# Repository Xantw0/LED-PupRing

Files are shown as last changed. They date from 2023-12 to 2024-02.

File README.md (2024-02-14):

<p align="center"> 
 
</p>

# 🌈 LED-PupRing
A collection of 3D files and build instructions to build a LED Nose Ring for neoprene Pup Masks



# 🛠 How to build?
Please check the [How-To guide](HOWTO.md) on build instructions and bill of materials

# 🤔 Too lazy to build yourself?
**I can probably help you out!**

I'll probably open my services every now and then, but do check this [Mastodon post](https://rubber.social/@Xantw0/111569252257938835) for more info on price, availability and contact info.

# ✨ Thanks
This project was inpired by [gdog](https://woof.group/@gdog) and Icteryn from this [Mastodon post](https://woof.group/@gdog/111154452751612377). I was playing around in Fusion360 and that got me to learn FreeCAD, so the logical thing was to share this dumb project with you too.

Also thanks to [Hex](https://linktr.ee/puphex) for his help showing me pictures and refrences of some of his hoods to make sure my mesurements were correct!

# ⚖ License
  <p xmlns:cc="http://creativecommons.org/ns#" xmlns:dct="http://purl.org/dc/terms/"><a property="dct:title" rel="cc:attributionURL" href="https://github.com/Xantw0/LED-PupRing">LED-PupRing</a> by <a rel="cc:attributionURL dct:creator" property="cc:attributionName" href="https://xantw0.link">Xantw0</a> is licensed under <a href="http://creativecommons.org/licenses/by-sa/4.0/?ref=chooser-v1" target="_blank" rel="license noopener noreferrer" style="display:inline-block;">Attribution-ShareAlike 4.0 International</a></p>

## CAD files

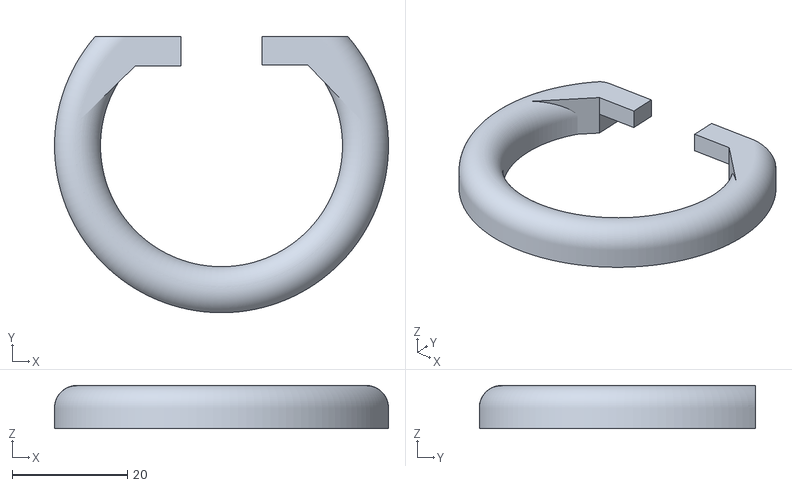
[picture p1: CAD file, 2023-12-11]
Print Files/NoseRingLED-Full.stl
58.0 x 48.0 x 7.50

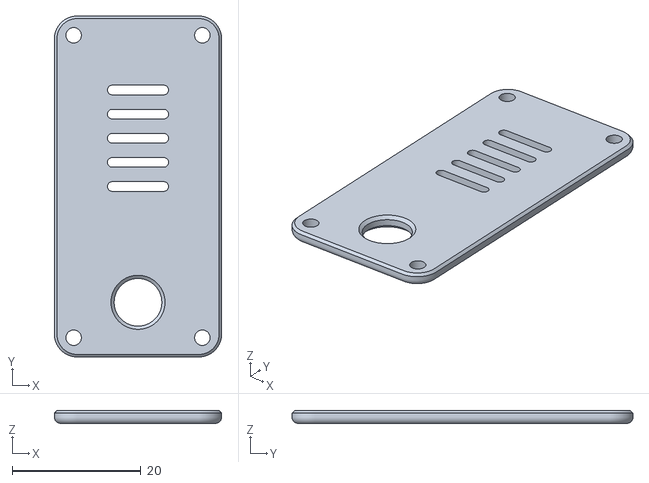
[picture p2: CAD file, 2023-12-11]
Print Files/NoseRingBox-Lid.stl
26.0 x 53.0 x 2.00

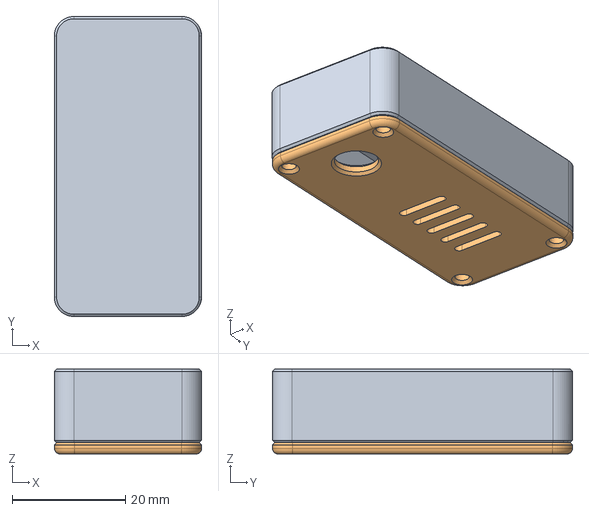
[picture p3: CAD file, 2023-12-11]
Source/NoseRingBox.FCStd
26.0 x 53.0 x 15.0 mm
Lid

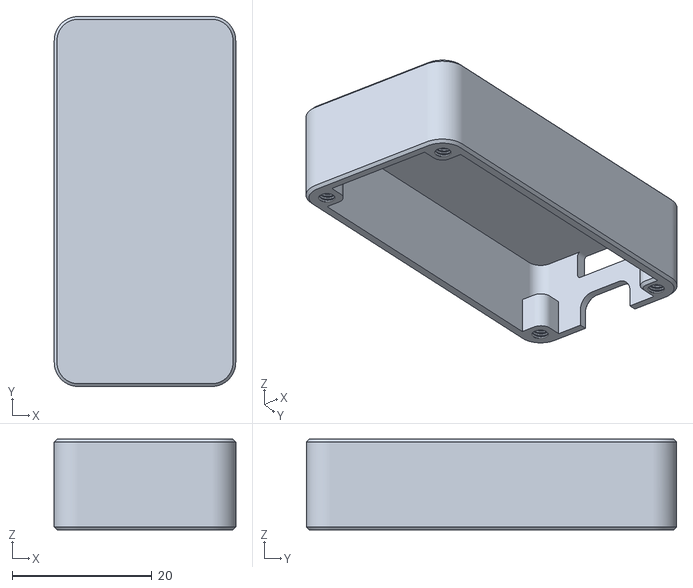
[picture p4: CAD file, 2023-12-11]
Print Files/NoseRingBox-Box.stl
26.0 x 53.0 x 13.0

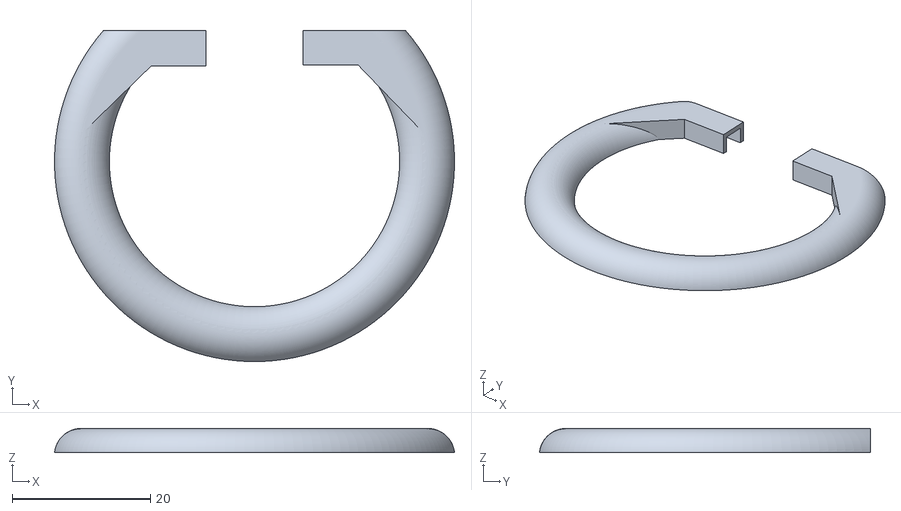
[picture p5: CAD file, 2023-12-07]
Print Files/NoseRingLED-Top.stl
57.9 x 48.0 x 3.50

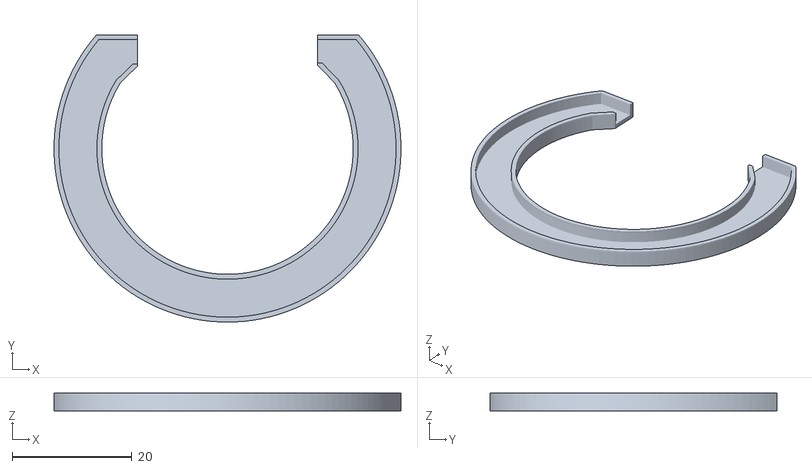
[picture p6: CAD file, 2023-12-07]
Print Files/NoseRingLED-Bottom.stl
58.0 x 48.0 x 3.00

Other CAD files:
Source/NoseRingLED.FCStd

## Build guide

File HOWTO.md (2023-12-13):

# Table of Content

1. [Bill of Material](#bill-of-material)
2. [Print Instructions](#print-instructions)
3. [Assembly Instruction](#assembly-instructions)
4. [Putting the Nose Ring on](#putting-the-nose-ring-on)

# Bill of Material
(Note: All of the link are **NOT** affiliated, I do not make money if you use these. Feel free to source your components elsewhere 😉)
<p align="center"> 

| Item | Amount | Price |
| --- | --- | --- |
| [Seeed Studio XIAO ESP32C3](https://vi.aliexpress.com/item/1005005382287176.html) | 1 | GBP 3.80 |
| [M2*8 Screws](https://www.amazon.co.uk/dp/B09SD91HGC) | 4 | GBP 0.09 |
| [White, Transparent or Glow In The Dark PLA (Nose Ring)](https://www.amazon.co.uk/dp/B0BPC7RCPT) | 4g | GBP 0.08 |
| [Black PLA (Control box)](https://www.amazon.co.uk/dp/B08JG35BNP) | 10g | GBP 0.20 |
| [Latching Push Button](https://www.amazon.co.uk/dp/B07BMNYJ13) | 1 | GBP 0.20 |
| [JST 3 pin cable](https://vi.aliexpress.com/item/4000450837340.html) | 1 pair | GBP 0.12 |
| [JST 2 pin cable](https://www.amazon.co.uk/gp/product/B08JVC4LVG) | 1 pair | GBP 0.60 |
| [3.7V Li-ion 502030 Battery 250mAh](https://www.amazon.co.uk/dp/B08FD3V6TF) | 1 | GBP 7.00 |
| [4mm width or less high density LED Strip](https://vi.aliexpress.com/item/4000765540185.html) | 30 Leds (approx) | GBP 2.00 |
| **TOTAL** | - | **GBP 14.09** |

</p>

***Note:** All prices are withouth shipping cost, and the total doesn't reflect the electricity or labour expenses*

# Print Instructions
## Ring
Print the **NoseRingLED-Top** and **NoseRingLED-Bottom** files

Use White, Transparent or Glow in the Dark PLA Filament
The rings are very thin, so infill will not do anything.
For mine, I print the Top part with the hole facing the bed with support to make sure I get a good finish, and the Bottom flat on the bed

<p align="center"> 
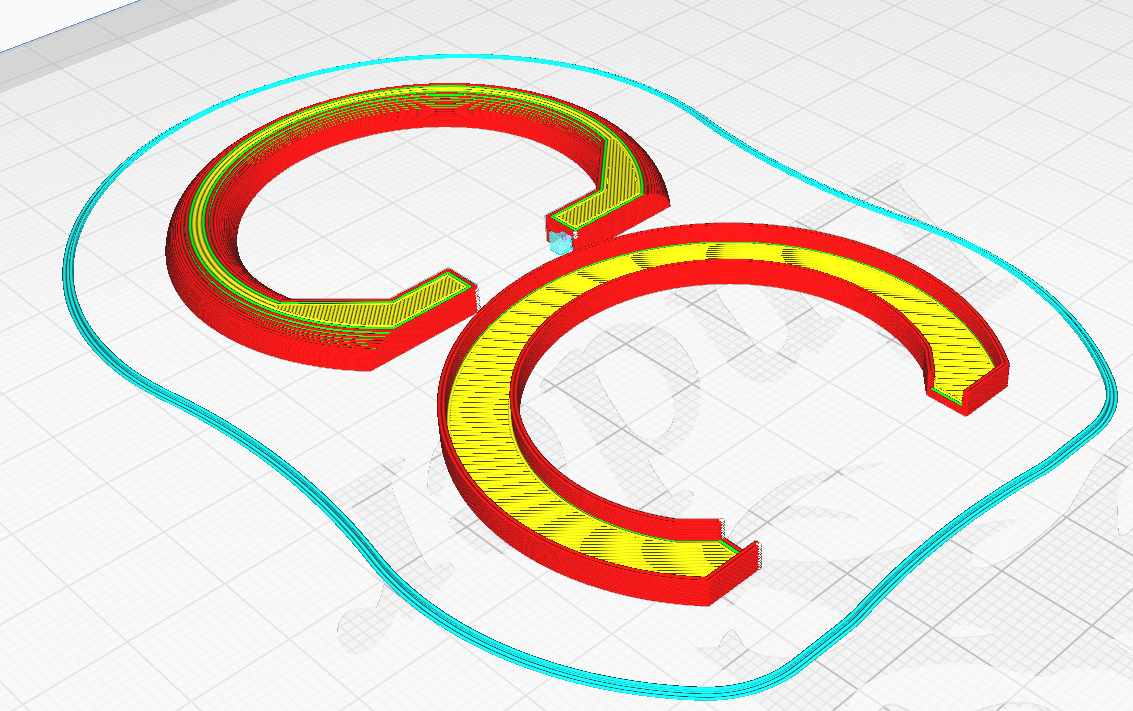
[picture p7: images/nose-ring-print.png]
Nose Ring print screenshot in Cura

</p>

## Control Box

Print the **NoseRingBox-Box** and **NoseRingBox-Lid** files

I recommend using PLA in black to blend with the muzzle, but you can use whatever you fancy.
Enable support everywhere for the USB port and the screws mount points

⚠ You might need to flip the model! Make sure to have the lid with the countersunk holes facing up, and the box flat on the bed

<p align="center"> 
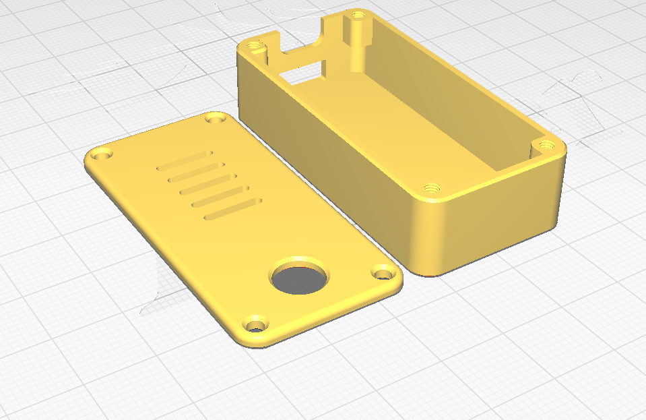
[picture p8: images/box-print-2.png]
Control Box Cura screenshot pre slice

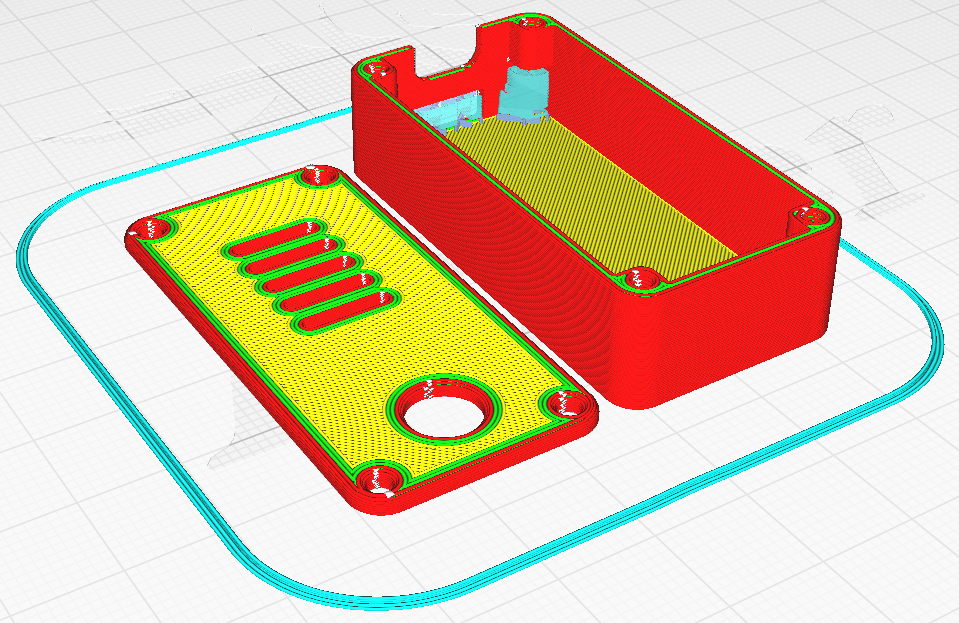
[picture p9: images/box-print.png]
Control Box Cura screenshot sliced

</p>

# Assembly Instructions
## Wiring

<p align="center"> 
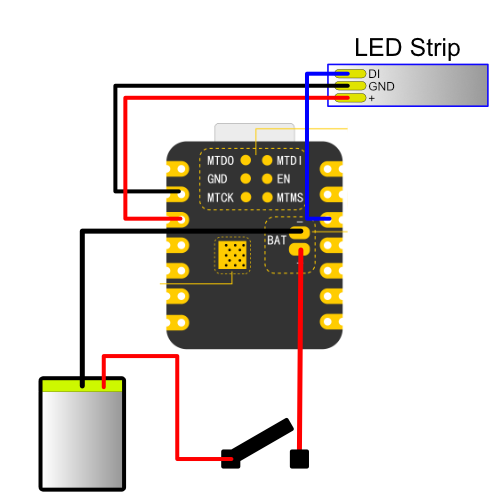
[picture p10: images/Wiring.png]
Wiring Diagram

</p>

## WLED Setup
You can use anything you want for the control of your nose ring, even do custom code, but for the sake of simplicity, you can also just use WLED

[You can find installation instructions here](https://kno.wled.ge/basics/install-binary/)

Once installed, make sure you set the LED Strip length correctly (30 Leds if using my BOM), and the Data Pin (D2 is GPIO 4, so put 4 in there)

## Battery life

Based on my tests, and for best longevity, you should set the maximum brightness of the LEDs to around 30%. 

More will be brighter, but probably not worth it, and at 30% the whole contraption uses aroun 30mAh, meaning on the battery suggested, you would get around 2 hours of battery life.

<p align="center"> 
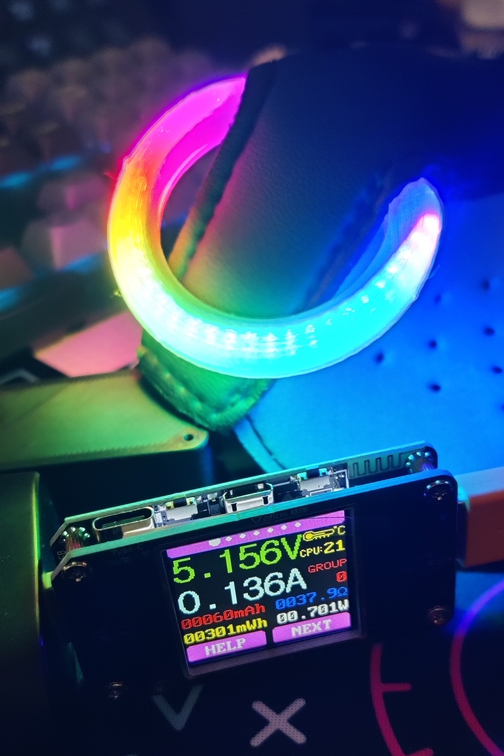
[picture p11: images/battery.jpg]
 
</p>

## Shoving it all in the box
1. Stick the wifi antenna to the bottom of the box 
2. Place the microcontroller upside down with the USB Port through the dedicated hole
3. Hotglue it into place to avoid having the controller be pushed back when plugging the USB in
4. Plug the battery + Push button on the JST connectro and put it where there is still some space sleft. Depending of the wire you are using, it might end up being a tight fit
5. Use super glue to put the push button through the cover hole. Feel free to use extra hotglue to keep it there
6. Feed the LED JST Connector out to be able to pug it to the ring later
7. Close the whole thing up and screw it in, **make sure you are not applying too much pressure on the battery or potentially puncturing it!**

<p align="center"> 
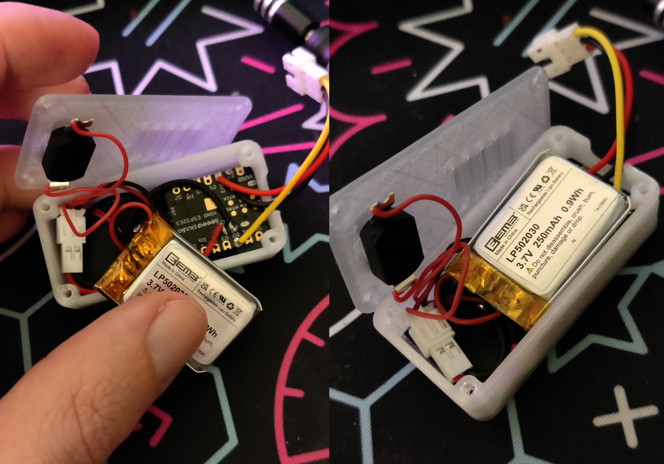
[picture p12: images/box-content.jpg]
Photo of the box content fitted in tightly
 
</p>

## Making the LED Ring
The instruction will make it sound simple, but dealing with miniature electronics is a huge pain.
1. Cut the right amount of LED to fit the whole curve of the ring (it depends on your strip and cut line, but aim for slightly less just in case). For me it's 30 LEDs
2. Peel the adhesive back and glues it on the bottom part of the ring, holding for a few minutes until it fits.
3. Make sure to feed the wires through the back and keep them out for the next part
4. Still using some suber glue, press and glue the top part over it. Depending on the LED used, the fit is VERY tight, so you will want to hold it for a few minutes and touch up with more glue to make it stick.

<p align="center"> 
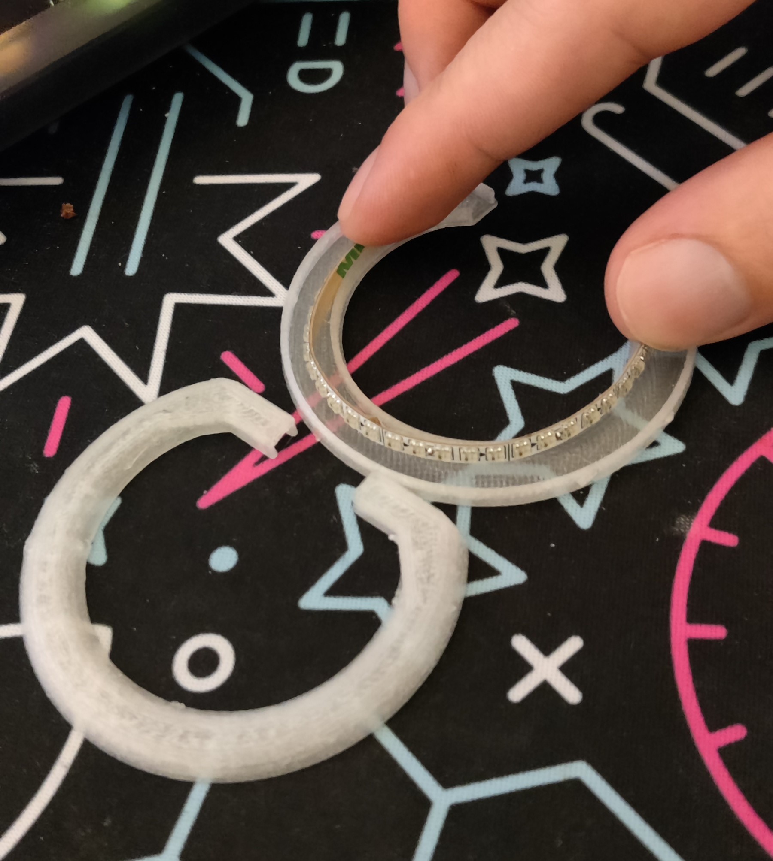
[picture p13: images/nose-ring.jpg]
 
</p>

# Putting the nose ring on
## Mr S Puppy Hood and Amazon/Aliexpress alternatives

<p align="center"> 
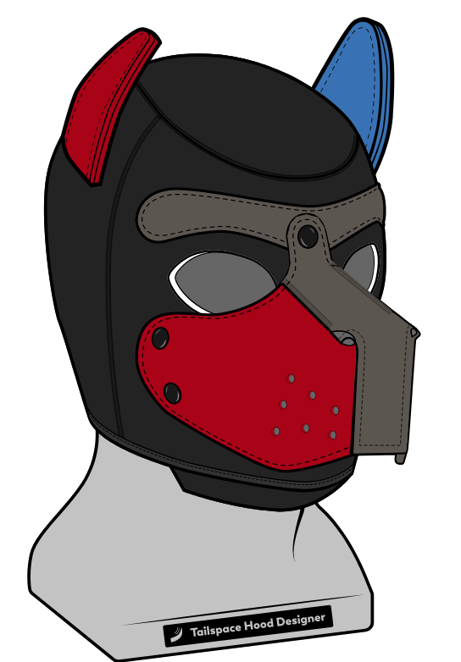
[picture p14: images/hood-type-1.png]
Tailspace hood designer screenshot of a Mr S Puppy hood
 
</p>

The only thing you will need to do is add a bit of velcro tape on the inside of the muzzle. Use super glue as the adhesive tape on the velcro will not hold to neoprene.

You can then feed the nose ring cable and ring itself by stretching the nose holes a bit.

<p align="center"> 
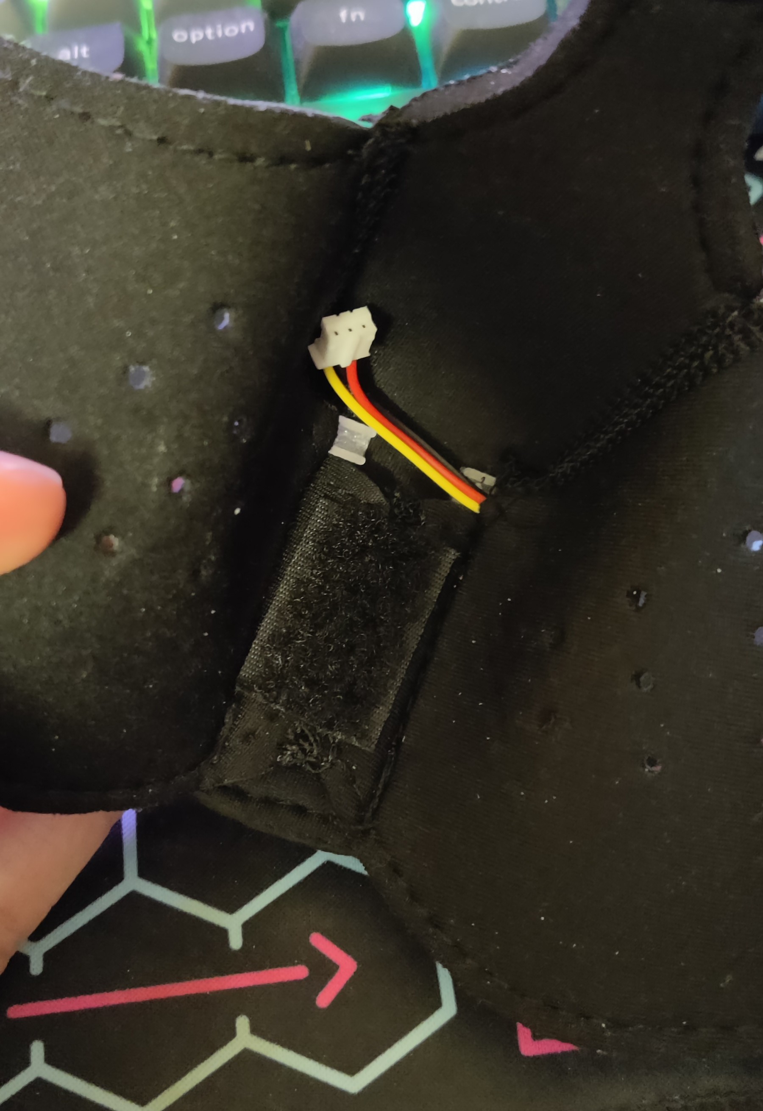
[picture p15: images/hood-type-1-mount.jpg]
Photo of the inside of the hood muzzle with the nose ring cable fed through and velcro tape glued
 
</p>

## Mr S K9 Hood and Frisky Hoods
<p align="center"> 
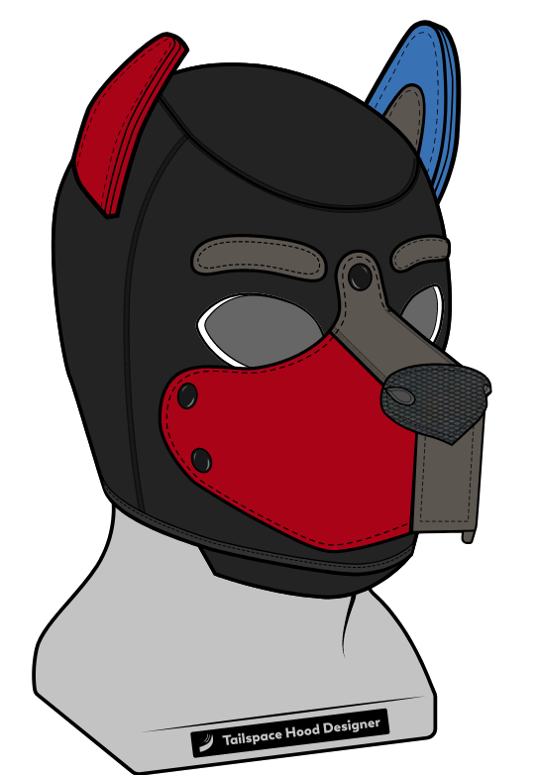
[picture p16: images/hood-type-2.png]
Tailspace hood designer screenshot of a Mr S K9 hood
 
</p>

For these, **you will have to put a hole on the backside of the muzzle to allow the nose ring cable to be fed through**. 

> ⚠ I cannot provie better instruction since I don't own (yet) these kind of hoods, so these are based of photos from friends and best attempt. Proceed with caution

While I tried to have as minimal of an impact on the hood, this is unfortunately unavoidable here, but the hole will be in the inside, so invisible, and just big enough to fit the JST connector

# ⚠ Caution
* Because of the way the SEEED Microcontroller battery posrt works, following my given instruction, you can only charge the device when it is on.
  > Any suggestion on making this better is welcomed 🙏

* Be **VERY CAREFUL** with the battery, it is a tiny and highly inflamable device very close to your face that can puff up and catch of fire if wired wrong. 
  * With flat cable and a bit of routing, you can probably power the contraption from an external battery.

* The device has not been tested for extended used over time, so I cannot assess if it will overheat, nor it's lifetime.

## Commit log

2023-12-11 Sizing fix for Mr S Hoods + Full ring
    [NoseRingBox-Box.stl, NoseRingBox-Lid.stl, NoseRingLED-Full.stl]
2023-12-11 Source file for size update
    [NoseRingBox.FCStd, NoseRingLED.FCStd]
2023-12-11 Countersunk lid mounting holes
    [NoseRingBox-Lid.stl, NoseRingBox.FCStd]
2023-12-11 Countersunk mounting holes for lid
    [NoseRingBox-Lid.stl, NoseRingBox.FCStd]
2023-12-12 Moved print files to dedicated folder
    [NoseRingBox-Box.stl, NoseRingBox-Lid.stl, NoseRingLED-Bottom.stl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]
2023-12-13 Added info on battery life
